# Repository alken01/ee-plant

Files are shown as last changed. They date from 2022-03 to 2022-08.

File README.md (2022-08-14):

# ee-plant 🌱
## EE5/IoT02
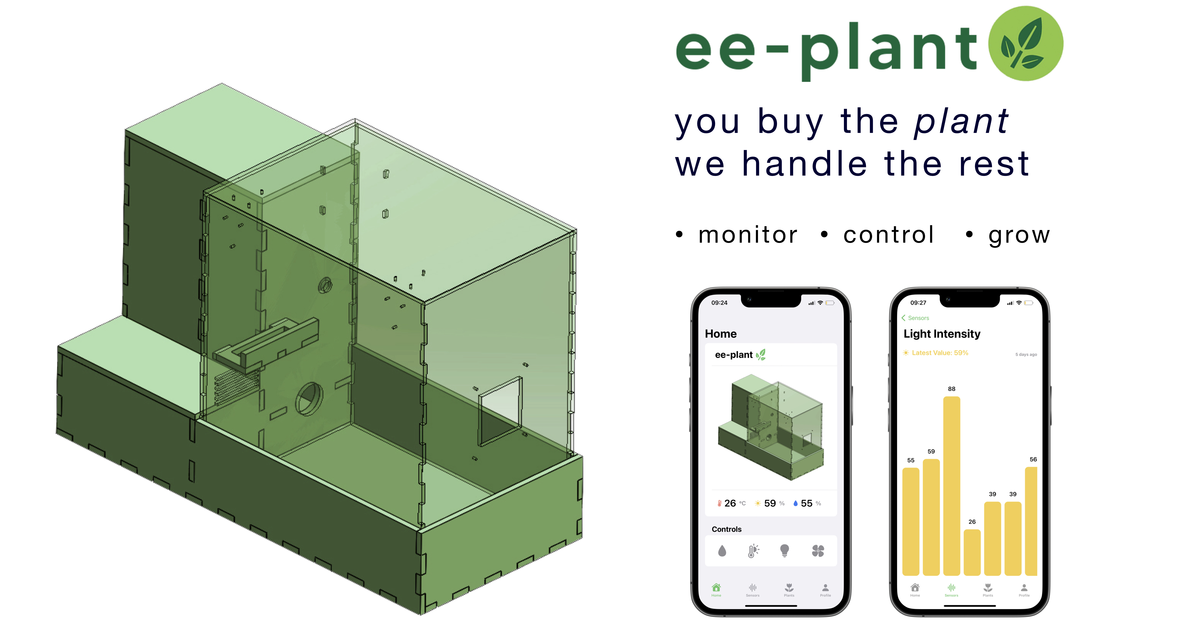
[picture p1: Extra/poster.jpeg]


### Intro
If you do not have the time to take care of your plants or when you are away from home for a few days, the ee-plant can help you! The system can look after different plant species, from common house plants to exotic ones. Specialised algorithms are designed with that in mind, tailored for every kind. 

The ee-plant comes with an Android app that updates the user about the plant. Is it too cold? The temperature goes up! Is it too dry? The system will water the plant. If the reservoir's water level is low, the app will notify the user.

Of course, you can take matters into your own hands and adjust every command accordingly.

### Sensors
The following sensors monitor the system 24/7:

- the soil moisture
- the air humidity
- temperature
- light intake

### Actuators
The following actuators regulate and control the system:

- a heater warms up the air
- a fan cools down the environment and regulates the humidity
- a spray machine, connected to a servo motor, sprays water and increase the humidity
- the water reservoir, attached with a pump and a servo motor, waters the soil

### Finally
The system's exterior is made out of a plexiglass box, MDF and 3D printed components. A power bank supplies the system with 5V. The ESP32 communicates with the database in the server through its Wi-Fi module. Data from the sensors is saved in these databases. It is then made available to the user via the app in form of graphs over time

> With the ee-plant everything is about nature and comfort.

## Sprints

### Sprint 1
In sprint 1 we worked mainly on the system's sensors.
The following user stories were closed:

- As a user I want to organise the data in databases
- As a user I want to know the temperature
- As a user I want to know the humidity and the moisture
- As a user I want to know the water level of the reservoir
- As a user I want to know if the plant is in light

[Video Sprint 1](https://kuleuven.mediaspace.kaltura.com/media/EE5+Team+IoT+2+-+Sprint+1/1_wgv9ouep)

### Sprint 2

The following user stories were closed:

- As a user I want to know the water level of the reservoir
- As a user I want to know if the plant is in light
- As a user I want to know the humidity and the moisture
- As a user I want to know the temperature
- As a user I want to organise the data in databases
- As a user I want a nice exterior design/case

Progress was made in the following:

- As a user I want to have a custom REST API
- As a user I want an Android App to control the device
- As a user I want to control the lighting

[Video Sprint 2](https://kuleuven.mediaspace.kaltura.com/media/EE5+Team+IoT+2+-+Sprint+2/1_kdvxv84o)

### Sprint 3

The following user stories were closed:

- As a user I want an iOS app to control the device
- As a user I want to have a smart device
- As a user I want everything to fit in the same case
- As a user I want to water the plant
- As a user I want to have web connectivity
- As a user I want to have as minimal wiring as possible (PCB)

[Video Sprint 3](https://kuleuven.mediaspace.kaltura.com/media/ee-plant+sprint+3+bew/1_60p68z9a)

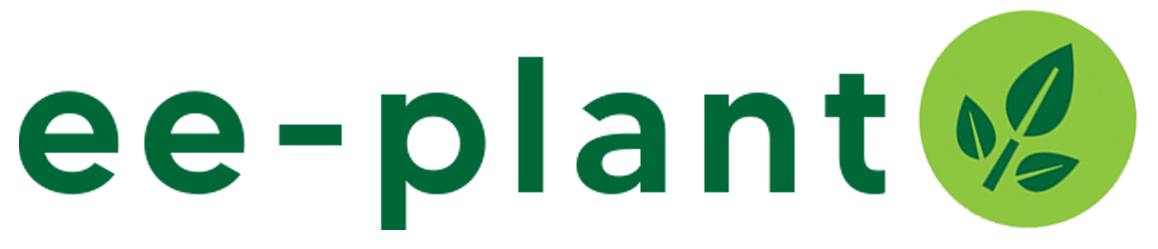
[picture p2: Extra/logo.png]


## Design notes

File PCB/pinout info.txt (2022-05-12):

Tussen twee pinnen 2,54 mm
Lengte van een rij = 11*2.54 = 27.94
Verticaal van elkaar verwijderd = 21.65

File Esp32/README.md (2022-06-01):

# _Sample project_

(See the README.md file in the upper level 'examples' directory for more information about examples.)

This is the simplest buildable example. The example is used by command `idf.py create-project`
that copies the project to user specified path and set it's name. For more information follow the [docs page](https://docs.espressif.com/projects/esp-idf/en/latest/api-guides/build-system.html#start-a-new-project)

## How to use example
We encourage the users to use the example as a template for the new projects.
A recommended way is to follow the instructions on a [docs page](https://docs.espressif.com/projects/esp-idf/en/latest/api-guides/build-system.html#start-a-new-project).

## Example folder contents

The project **sample_project** contains one source file in C language [main.c](main/AirHumidity.c). The file is located in folder [main](main).

ESP-IDF projects are built using CMake. The project build configuration is contained in `CMakeLists.txt`
files that provide set of directives and instructions describing the project's source files and targets
(executable, library, or both). 

Below is short explanation of remaining files in the project folder.

```
├── CMakeLists.txt
├── main
│   ├── CMakeLists.txt
│   └── main.c
└── README.md                  This is the file you are currently reading
```
Additionally, the sample project contains Makefile and component.mk files, used for the legacy Make based build system. 
They are not used or needed when building with CMake and idf.py.

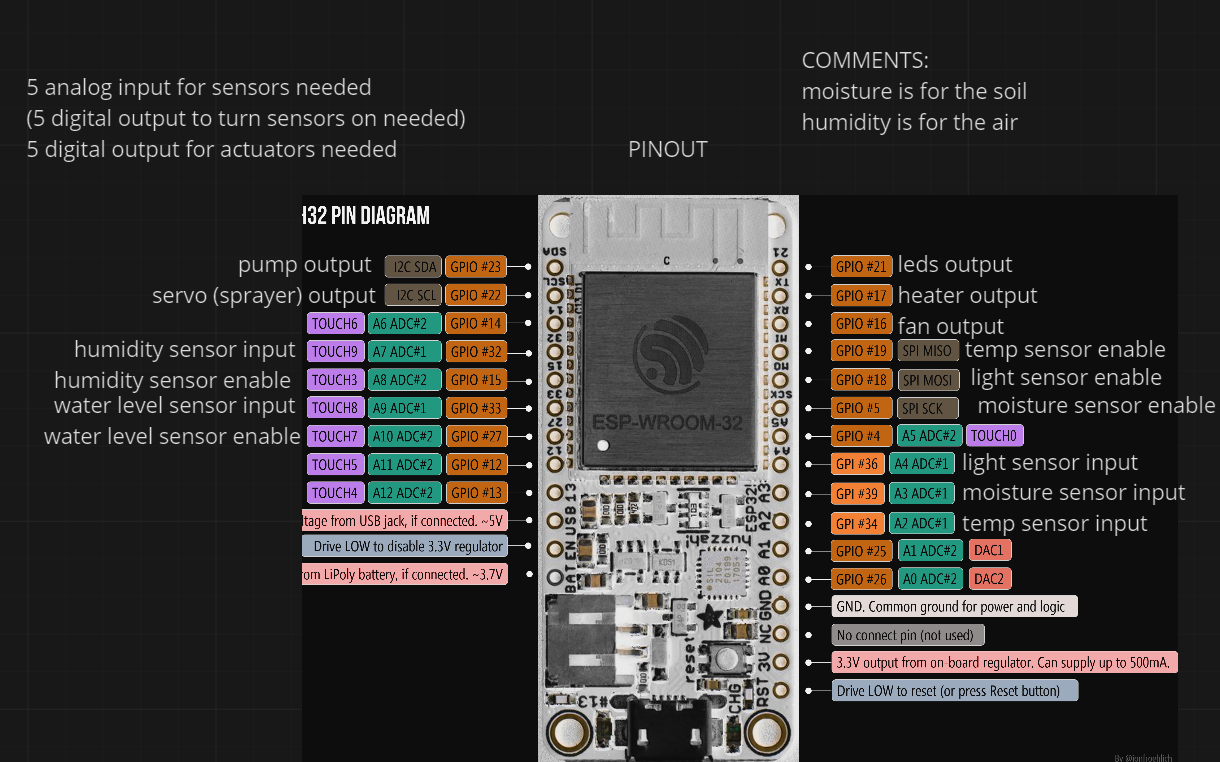
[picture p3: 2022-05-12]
PCB/image.png

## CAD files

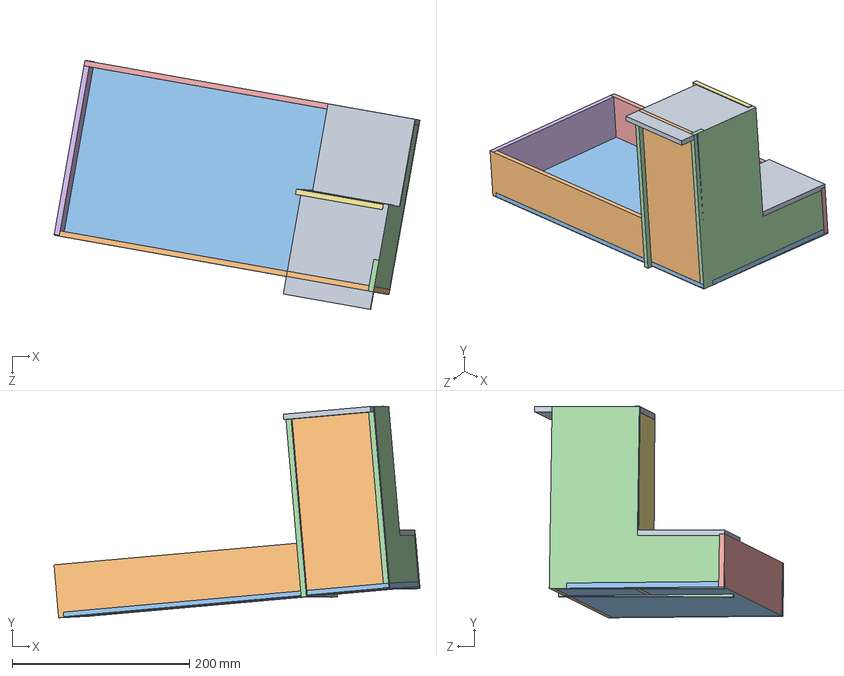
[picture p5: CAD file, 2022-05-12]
SolidWorks/Assembly 22.02.19.SLDASM
412.8 x 238.8 x 280.7 mm
PlantFront
PlantBottom
ReservoirFront x 2
PlantBack
ReservoirCover x 2
PlantSide
ReservoirSExtraLong

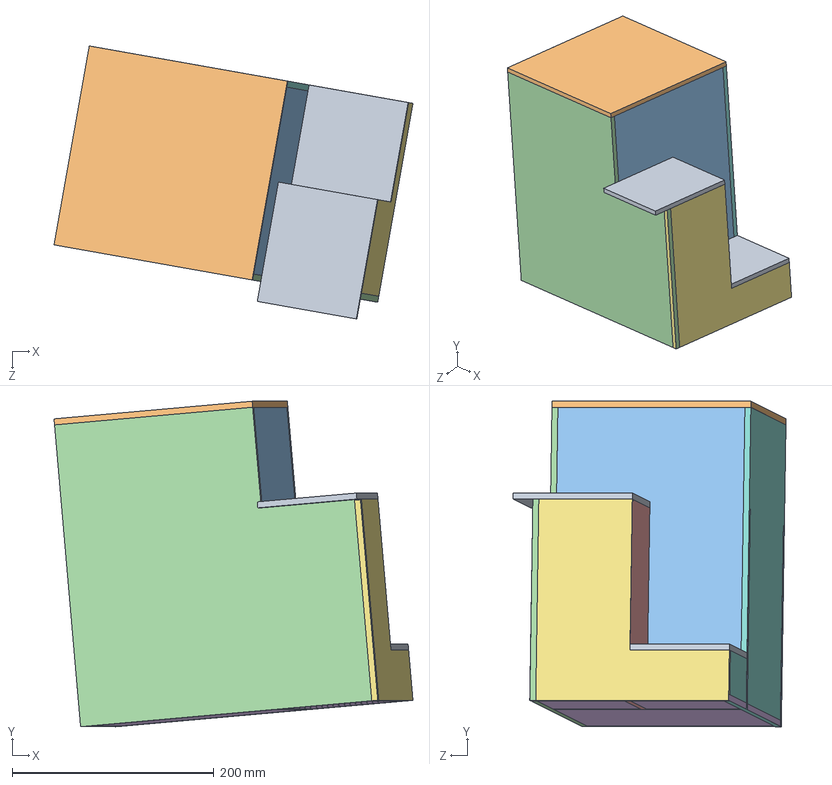
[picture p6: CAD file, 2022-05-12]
SolidWorks/Assembly1.SLDASM
355.5 x 322.4 x 270.4 mm
PlantSide x 2
PlantCover
PlantFront
ReservoirSExtraLong
PlantBottom
ReservoirFront
PlantBack
ReservoirCover x 2

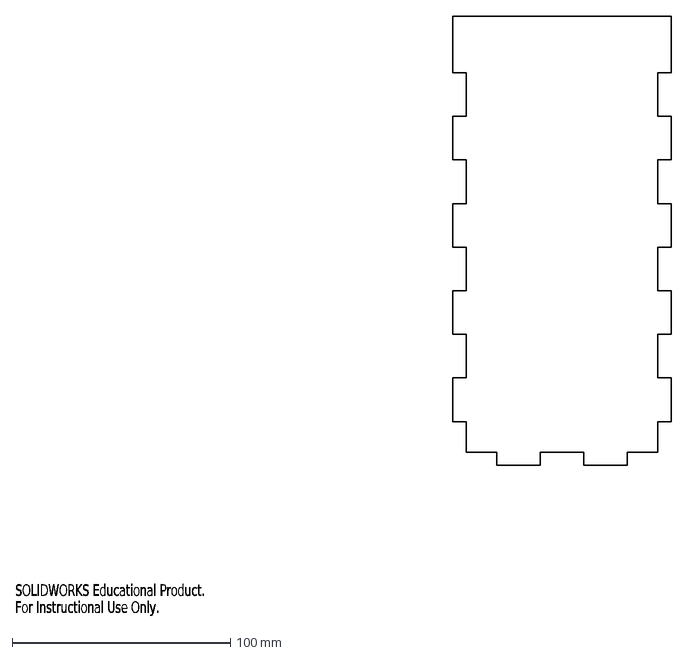
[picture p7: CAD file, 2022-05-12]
SolidWorks/drawings/ReservoirS.DXF
SOLIDWORKS Educational Product.
For Instructional Use Only.

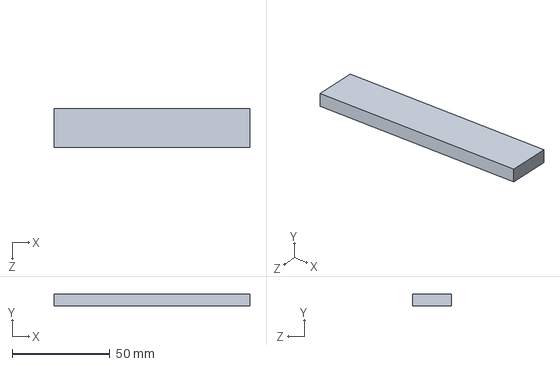
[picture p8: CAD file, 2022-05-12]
SolidWorks/Parts/FootballLight.SLDPRT
100.0 x 6.00 x 20.0 mm

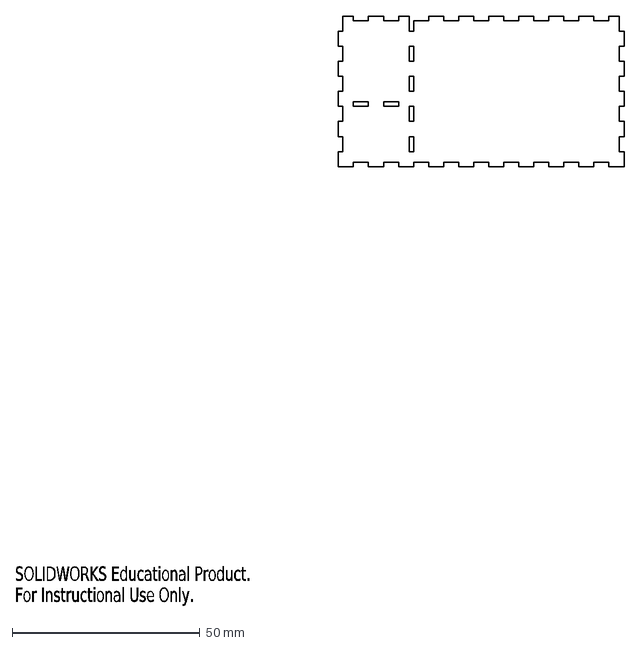
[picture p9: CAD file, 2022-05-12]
SolidWorks/drawings/PlantBottom.DXF
SOLIDWORKS Educational Product.
For Instructional Use Only.

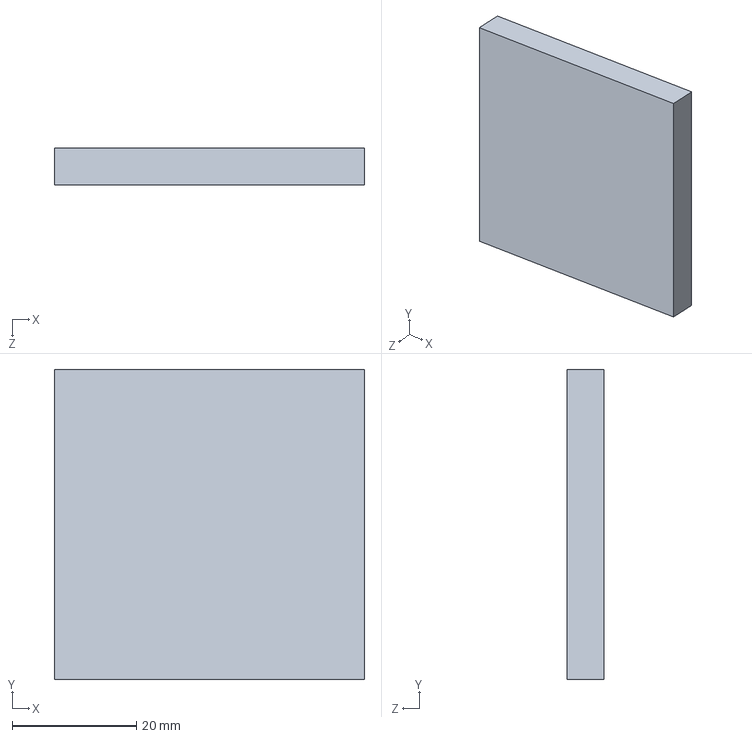
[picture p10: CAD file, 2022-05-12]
SolidWorks/Parts/ElectronicsSide.SLDPRT
50.0 x 50.0 x 6.00 mm

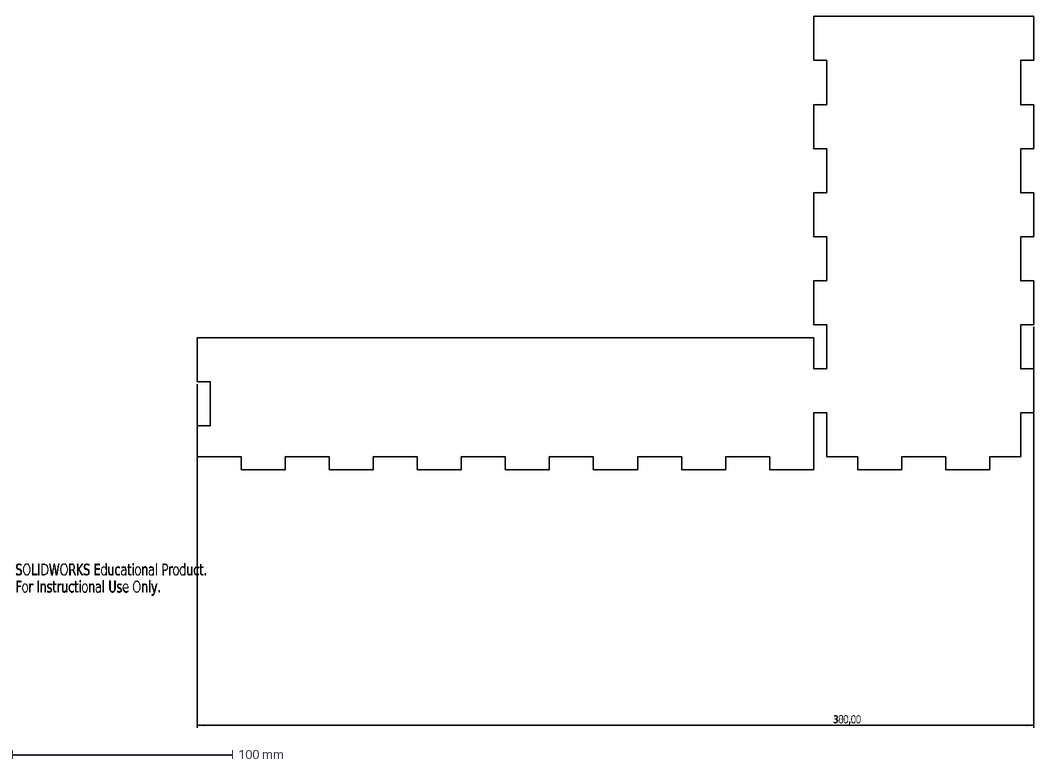
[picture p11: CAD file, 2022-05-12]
SolidWorks/drawings/PlantFront.DXF
380,00
SOLIDWORKS Educational Product.
For Instructional Use Only.

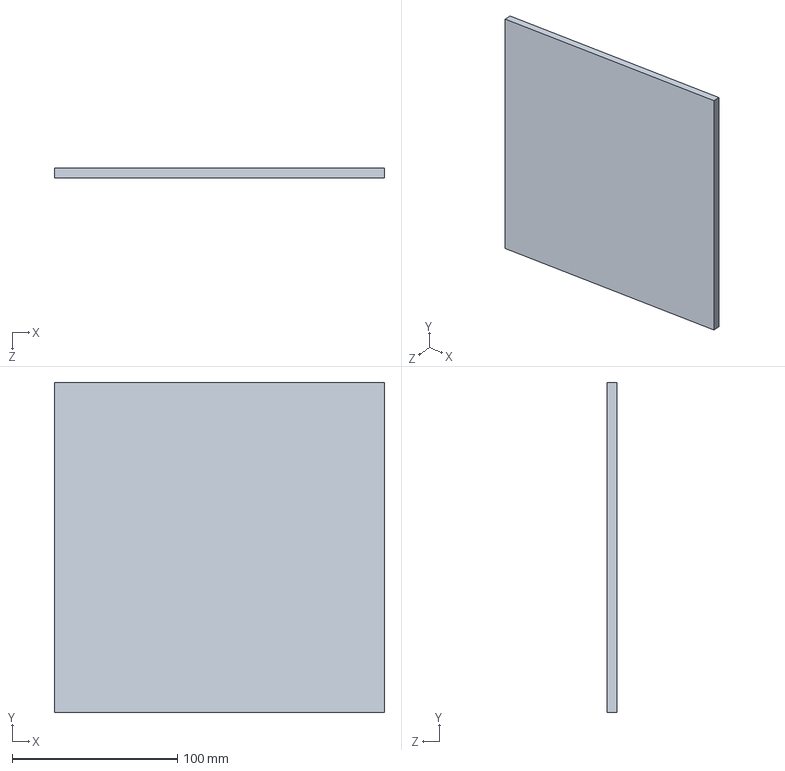
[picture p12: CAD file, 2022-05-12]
SolidWorks/Parts/PlantCover.SLDPRT
200.0 x 200.0 x 6.00 mm

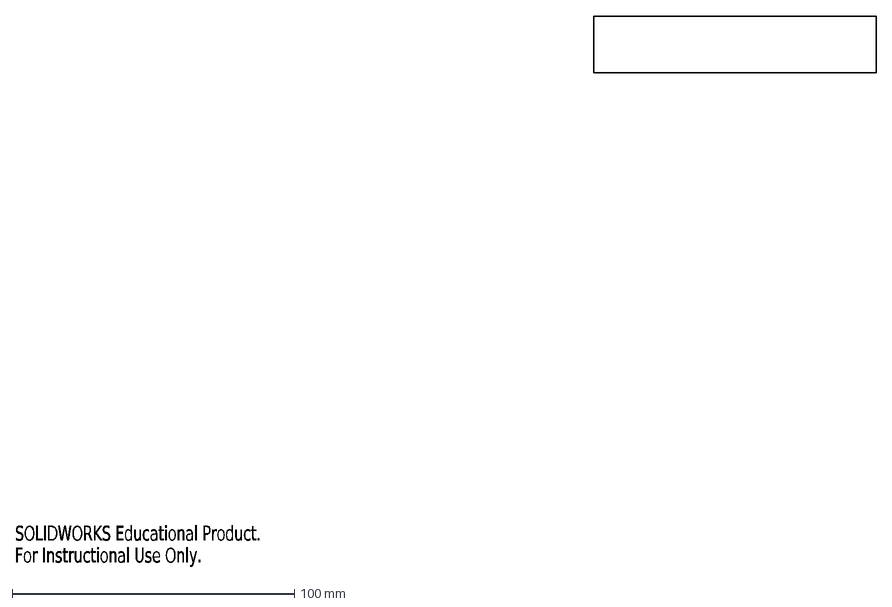
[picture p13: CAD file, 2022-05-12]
SolidWorks/drawings/FootballLight.DXF
SOLIDWORKS Educational Product.
For Instructional Use Only.

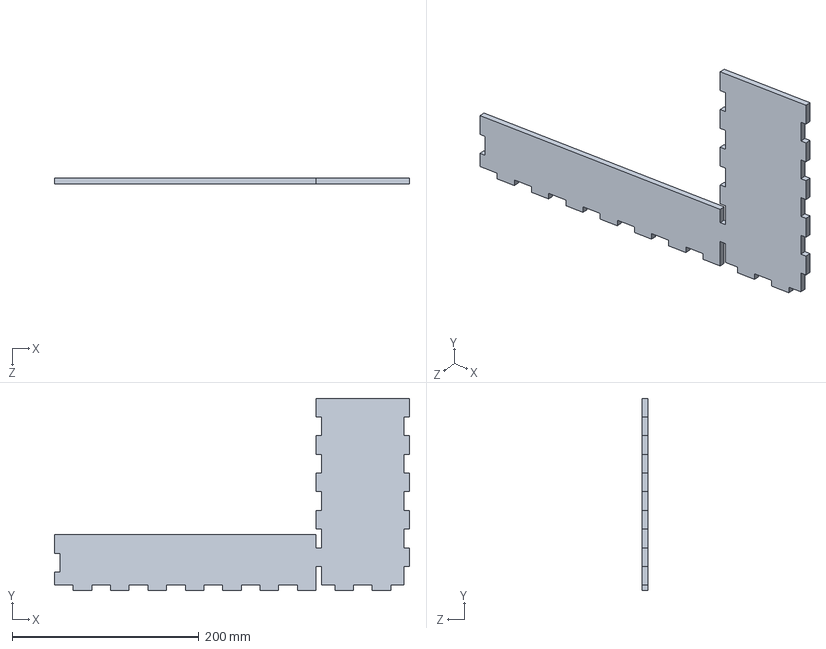
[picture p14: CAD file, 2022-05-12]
SolidWorks/Parts/PlantFront.SLDPRT
380.0 x 206.0 x 6.00 mm

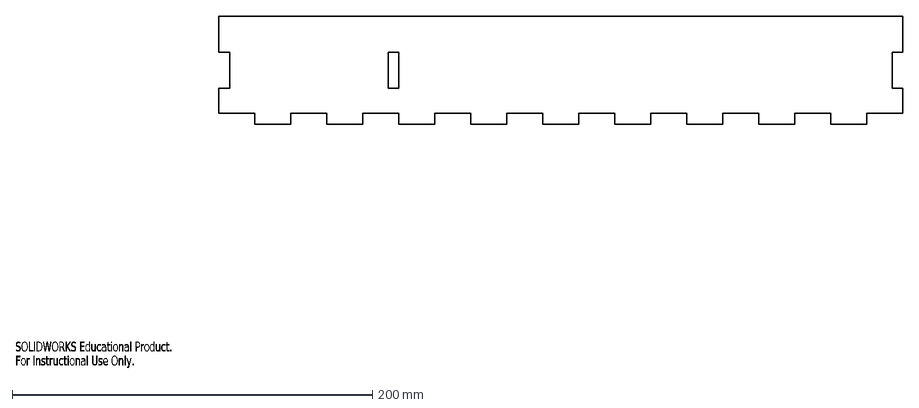
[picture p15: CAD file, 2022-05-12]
SolidWorks/drawings/PlantBack.DXF
SOLIDWORKS Educational Product.
For Instructional Use Only.

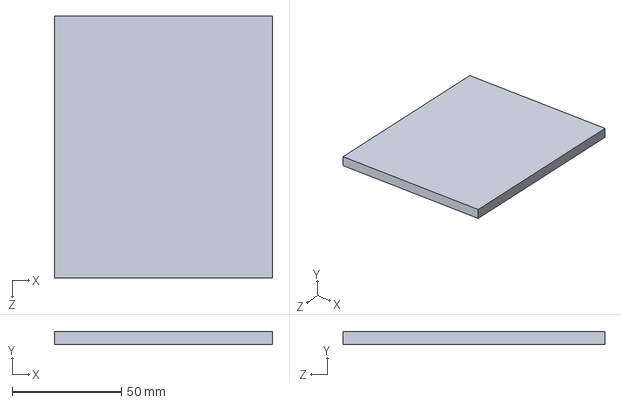
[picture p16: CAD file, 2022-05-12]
SolidWorks/Parts/ReservoirCover.SLDPRT
100.0 x 6.00 x 120.0 mm

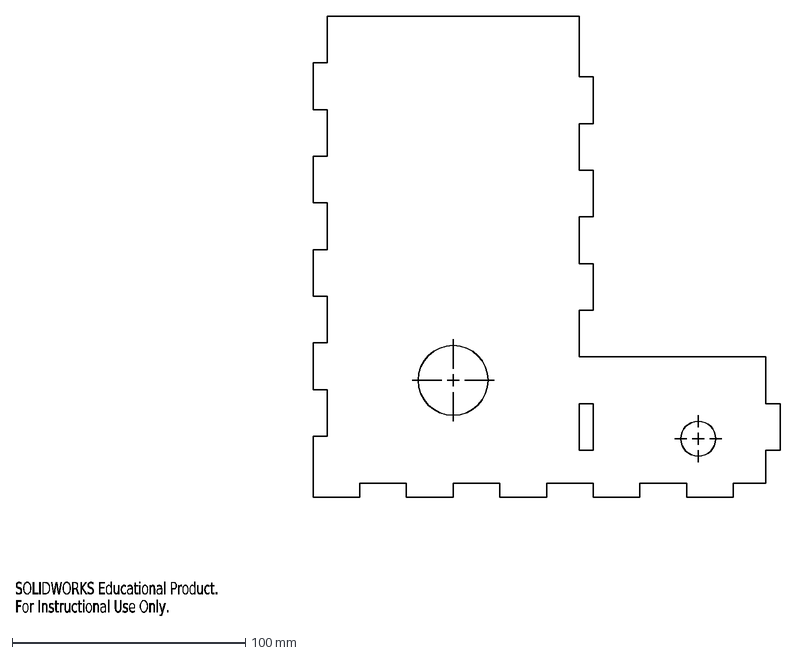
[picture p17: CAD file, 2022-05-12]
SolidWorks/drawings/ReservoirFront.DXF
SOLIDWORKS Educational Product.
For Instructional Use Only.

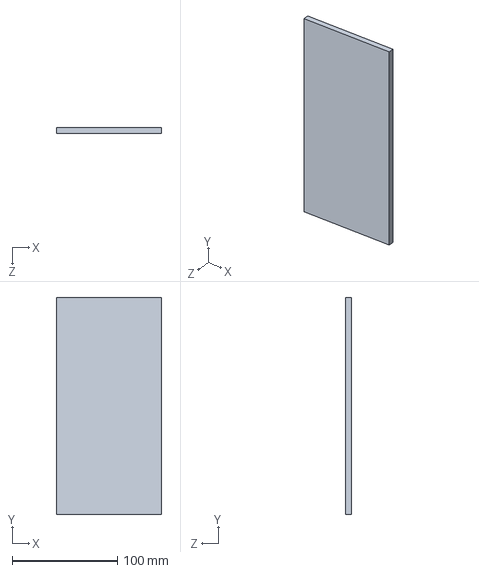
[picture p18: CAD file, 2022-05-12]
SolidWorks/Parts/ReservoirSExtraLong.SLDPRT
100.0 x 206.0 x 6.00 mm

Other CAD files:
SolidWorks/drawings/PlantCover.DXF
SolidWorks/Parts/ReservoirFrontNoHoles.SLDPRT
SolidWorks/drawings/ReservoirCover.DXF
SolidWorks/Parts/ElectronicsCover.SLDPRT
SolidWorks/Parts/ElectronicsFrontBack.SLDPRT
SolidWorks/Parts/MDFSide.SLDPRT
SolidWorks/Parts/PlantBack.SLDPRT
SolidWorks/Parts/PlantBottom.SLDPRT
SolidWorks/Parts/PlantSide.SLDPRT
SolidWorks/Parts/PlexiCover.SLDPRT
SolidWorks/Parts/PlexiFront.SLDPRT
SolidWorks/Parts/PlexiFrontNoHOles.SLDPRT
SolidWorks/Parts/ReservoirFront.SLDPRT
SolidWorks/Parts/ReservoirS.SLDPRT
SolidWorks/drawings/ElectronicsCover.DXF
SolidWorks/drawings/PlantSide.DXF
SolidWorks/drawings/ReservoirFront.SLDDRW
SolidWorks/drawings/ReservoirFrontNoHoles.DXF
SolidWorks/drawings/ReservoirSExtraLong.DXF

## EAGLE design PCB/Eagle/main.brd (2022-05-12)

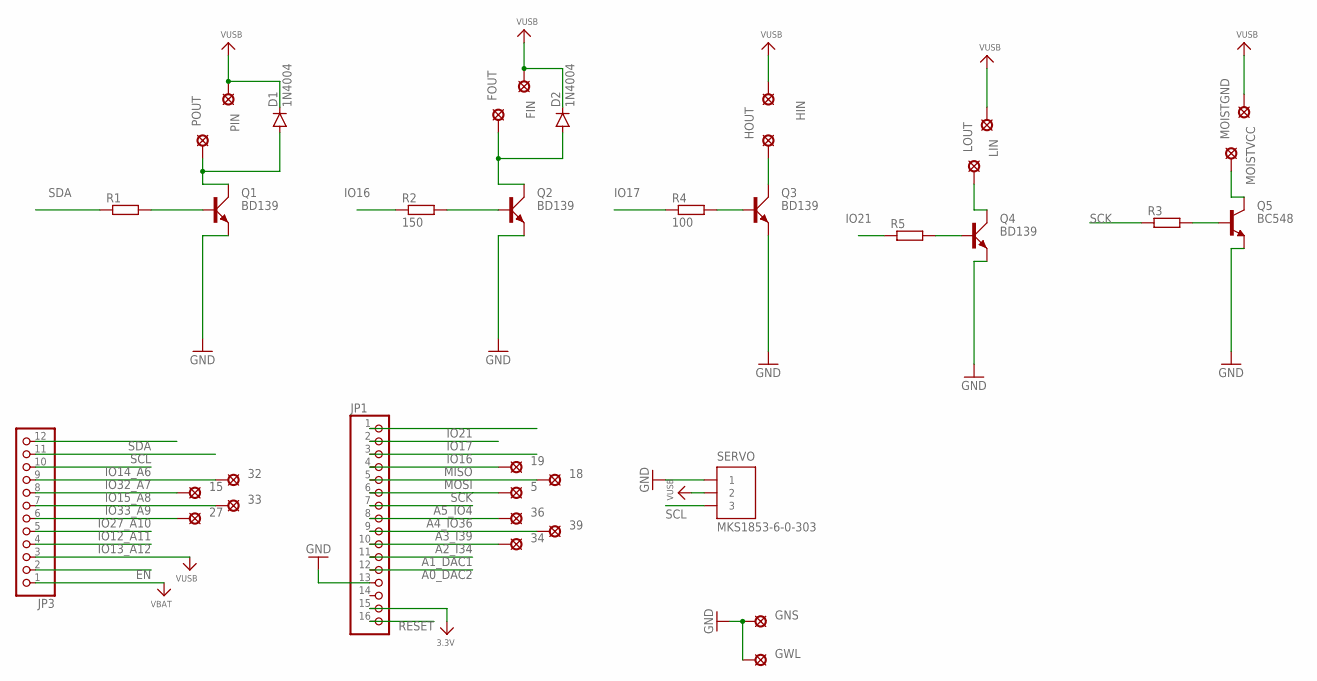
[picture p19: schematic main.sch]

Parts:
5, 15, 18, 19, 27, 32, 33, 34, 36, 39: SE13
D1, D2: 1N4004; DO41-10
FIN: SE13
FOUT: SE13
GNS: SE13
GWL: SE13
HIN: SE13
HOUT: SE13
JP1: HEADER-1X16_MIN; 1X16_ROUND_MIN
JP3: HEADER-1X12_MIN; 1X12_ROUND_MIN
LIN: SE13
LOUT: SE13
MOISTGND: SE13
MOISTVCC: SE13
PIN: SE13
POUT: SE13
Q1, Q2, Q3, Q4: BD139; TO126AV
Q5: BC548; TO92-EBC
R1, R3, R5: R-EU_R0805; R0805
R2: 150; R0805
R4: 100; R0805
SERVO: MKS1853-6-0-303

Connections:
3.3V: JP1.15
A0_DAC2: JP1.12
A1_DAC1: JP1.11
A2_I34: 34.MP, JP1.10
A3_I39: 39.MP, JP1.9
A4_IO36: 36.MP, JP1.8
A5_IO4: JP1.7
EN: JP3.2
GND: GNS.MP, GWL.MP, JP1.13, Q1.E, Q2.E, Q3.E, Q4.E, Q5.E, SERVO.1
IO12_A11: JP3.5
IO13_A12: JP3.4
IO14_A6: JP3.10
IO15_A8: 15.MP, JP3.8
IO16: JP1.3, R2.1
IO17: JP1.2, R4.1
IO21: JP1.1, R5.1
IO27_A10: 27.MP, JP3.6
IO32_A7: 32.MP, JP3.9
IO33_A9: 33.MP, JP3.7
MISO: 19.MP, JP1.4
MOSI: 18.MP, JP1.5
unnamed: Q4.B, R5.2
unnamed: Q3.B, R4.2
unnamed: LOUT.MP, Q4.C
unnamed: HOUT.MP, Q3.C
unnamed: D2.A, FOUT.MP, Q2.C
unnamed: Q2.B, R2.2
unnamed: D1.A, POUT.MP, Q1.C
unnamed: Q1.B, R1.2
unnamed: Q5.B, R3.2
unnamed: MOISTGND.MP, Q5.C
RESET: JP1.16
SCK: 5.MP, JP1.6, R3.1
SCL: JP3.11, SERVO.3
SDA: JP3.12, R1.1
VBAT: JP3.1
VBUS: D1.C, D2.C, FIN.MP, HIN.MP, JP3.3, LIN.MP, MOISTVCC.MP, PIN.MP, SERVO.2

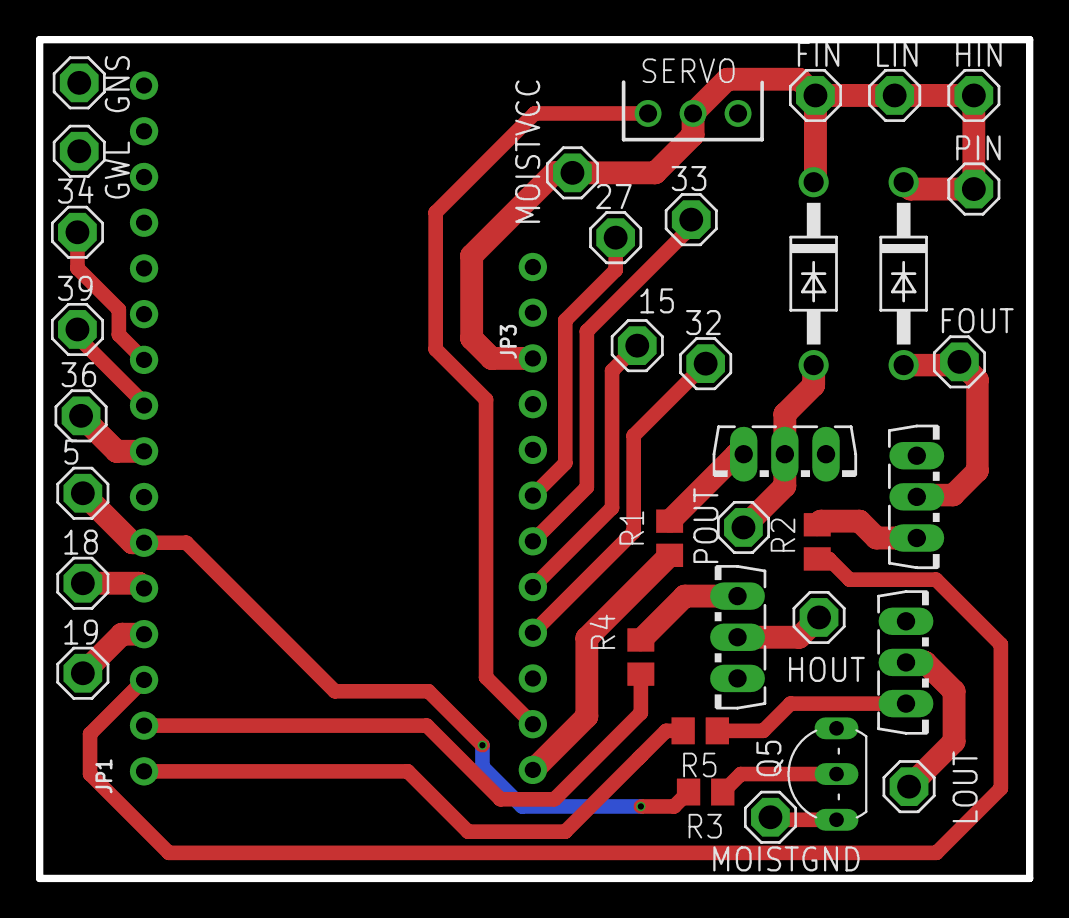
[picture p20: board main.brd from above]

Board: 2 copper layers, 55.0 x 46.6 mm, 37 parts (0 on the bottom side), 27 nets.

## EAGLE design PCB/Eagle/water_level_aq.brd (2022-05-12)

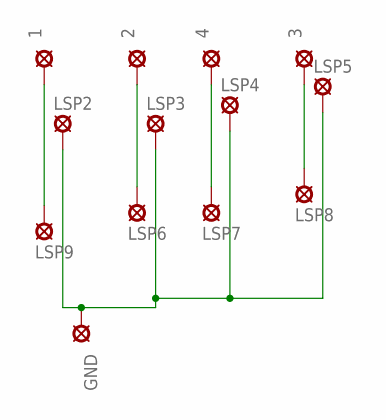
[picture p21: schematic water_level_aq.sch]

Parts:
1, 2, 3, 4: SE13
GND: SE13
LSP2, LSP3, LSP4, LSP5, LSP6, LSP7, LSP8, LSP9: MCS10B

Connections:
unnamed: 1.MP, LSP9.MP
unnamed: GND.MP, LSP2.MP, LSP3.MP, LSP4.MP, LSP5.MP
unnamed: 2.MP, LSP6.MP
unnamed: 4.MP, LSP7.MP
unnamed: 3.MP, LSP8.MP

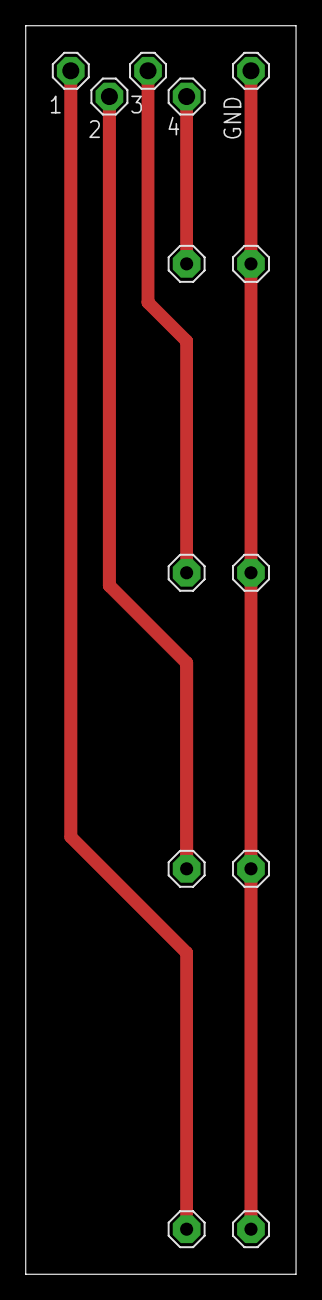
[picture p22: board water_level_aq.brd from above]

Board: 2 copper layers, 21.0 x 97.0 mm, 13 parts (0 on the bottom side), 5 nets.

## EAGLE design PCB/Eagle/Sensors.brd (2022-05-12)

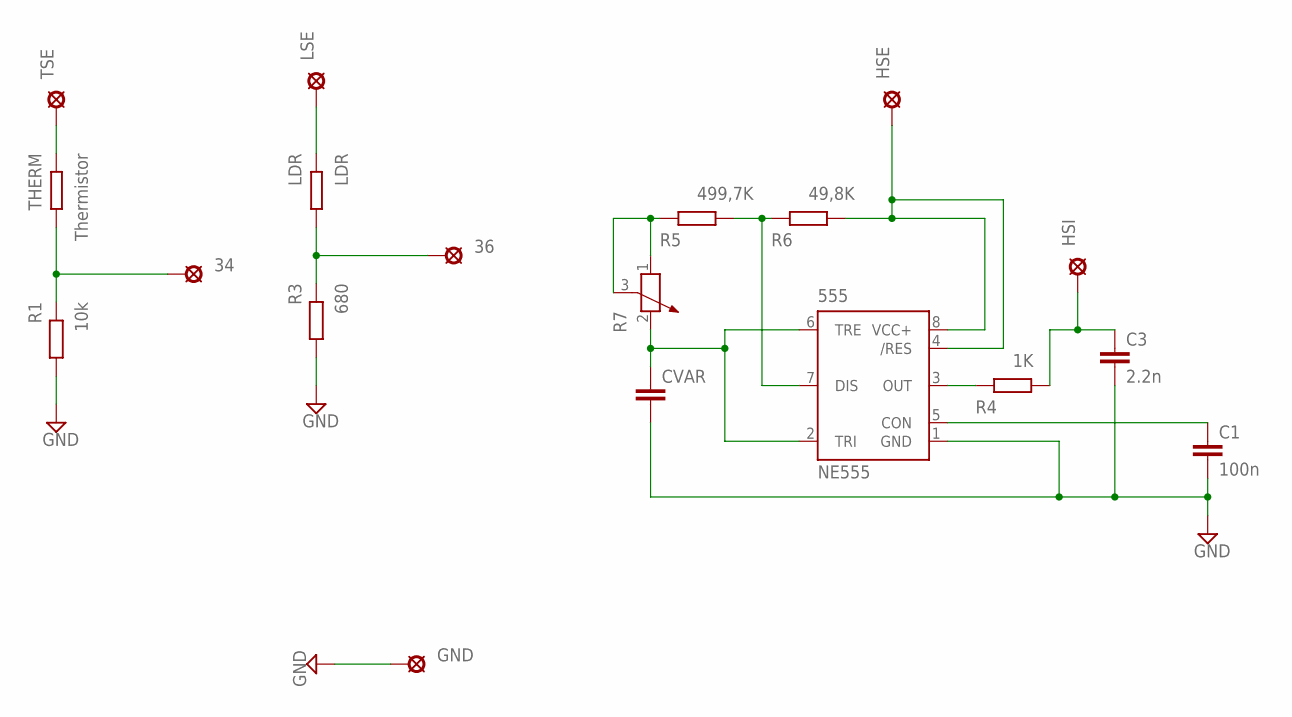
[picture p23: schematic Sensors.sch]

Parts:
34: SE13
36: 36; SE13
555: NE555; DIL-08
C1: 100n; C0805
C3: 2.2n; C0805
CVAR: C-EU050-025X075; C050-025X075
GND: SE13
HSE: SE13
HSI: SE13
LDR: LDR; WEERSTAND
LSE: SE13
R1: 10k; R0805
R3: 680; R0805
R4: 1K; R0805
R5: 499,7K; R0805
R6: 49,8K; R0805
R7: POTENTIOMETER_PT-10; PT-10
THERM: Thermistor; WEERSTAND
TSE: SE13

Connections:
34: 34.MP, R1.1, THERM.P$2
36: 36.MP, LDR.P$2, R3.1
GND: 555.1 (GND), C1.2, C3.2, CVAR.2, GND.MP, R1.2, R3.2
unnamed: THERM.P$1, TSE.MP
unnamed: LDR.P$1, LSE.MP
unnamed: 555.5 (CON), C1.1
unnamed: C3.1, HSI.MP, R4.2
unnamed: 555.3 (OUT), R4.1
unnamed: 555.4 (/RES), 555.8 (VCC+), HSE.MP, R6.2
unnamed: 555.2 (TRI), 555.6 (TRE), CVAR.1, R7.2
unnamed: R5.1, R7.1, R7.3
unnamed: 555.7 (DIS), R5.2, R6.1

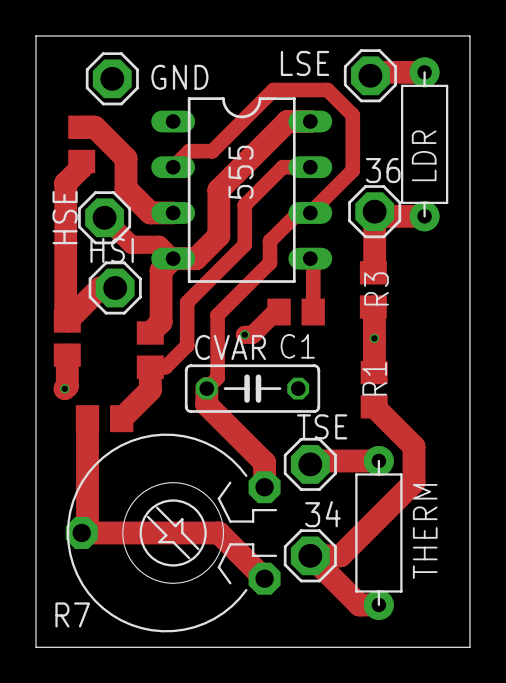
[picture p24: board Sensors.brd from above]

Board: 2 copper layers, 24.1 x 34.0 mm, 19 parts (0 on the bottom side), 12 nets.

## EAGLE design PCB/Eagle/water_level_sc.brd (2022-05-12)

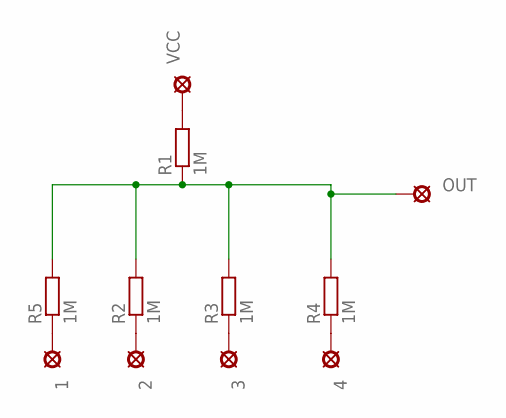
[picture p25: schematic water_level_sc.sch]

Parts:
1, 2, 3, 4: SE13
OUT: SE13
R1, R2, R3, R4, R5: 1M; R0805
VCC: SE13

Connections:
unnamed: 4.MP, R4.1
unnamed: 3.MP, R3.1
unnamed: 2.MP, R2.1
unnamed: 1.MP, R5.1
unnamed: R1.2, VCC.MP
unnamed: OUT.MP, R1.1, R2.2, R3.2, R4.2, R5.2

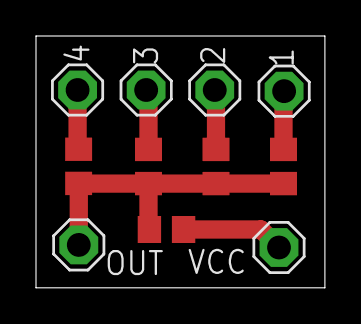
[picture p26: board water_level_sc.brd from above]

Board: 2 copper layers, 16.1 x 14.0 mm, 11 parts (0 on the bottom side), 6 nets.

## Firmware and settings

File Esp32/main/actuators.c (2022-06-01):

#include "appMain.h"
#include "actuators.h"
#include "water_pump.h"
#include <driver/ledc.h>


#define HEATER_OUTPUT_GPIO GPIO_NUM_17
#define FAN_OUTPUT_GPIO GPIO_NUM_16
#define LIGHT_OUTPUT_GPIO GPIO_NUM_21

ledc_channel_config_t ledc_heater_channel;



void config_heater_PWM(){
    ledc_timer_config_t ledc_timer = {
            .duty_resolution = LEDC_TIMER_13_BIT, // resolution of PWM duty
            .freq_hz = 5000,                      // frequency of PWM signal
            .speed_mode = LEDC_HIGH_SPEED_MODE,           // timer mode
            .timer_num = LEDC_TIMER_0,            // timer index
            .clk_cfg = LEDC_AUTO_CLK,              // Auto select the source clock
    };
    ledc_timer_config(&ledc_timer);

    ledc_heater_channel.channel = LEDC_CHANNEL_0;
    ledc_heater_channel.duty=0;
    ledc_heater_channel.gpio_num=HEATER_OUTPUT_GPIO;
    ledc_heater_channel.speed_mode=LEDC_HIGH_SPEED_MODE;
    ledc_heater_channel.hpoint=0;
    ledc_heater_channel.timer_sel=LEDC_TIMER_0;
    ledc_heater_channel.flags.output_invert=0;
    ledc_channel_config(&ledc_heater_channel);
}

void set_heater_pwm()
{
    ledc_set_duty(ledc_heater_channel.speed_mode, ledc_heater_channel.channel, 4000);
    ledc_update_duty(ledc_heater_channel.speed_mode, ledc_heater_channel.channel);
}

void reset_heater_pwm()
{
    ledc_set_duty(ledc_heater_channel.speed_mode, ledc_heater_channel.channel, 0);
    ledc_update_duty(ledc_heater_channel.speed_mode, ledc_heater_channel.channel);
}


_Noreturn void start_actuators(void* arg){
    config_heater_PWM();


    int light_flag=0;
    int fan_flag=0;
    int water_flag=0;
    int heater_flag=0;

    double temperature_value=0;
    double soil_moisture_value=0;
    int water_level_value=0;
    double light_value=300;



    while(1){
        //read from queues:
        struct sensor_flag_struct sensor_flag_received;
        for(int i=0; i < 4; i++){
            xQueueReceive(flag_queue,&sensor_flag_received, 100);
            if(sensor_flag_received.sensor_ID==0){ //water
                water_flag=sensor_flag_received.sensor_flag;
            }
            else if(sensor_flag_received.sensor_ID==1){ //heater
                heater_flag= sensor_flag_received.sensor_flag;
            }
            else if(sensor_flag_received.sensor_ID==2){ //lights
                light_flag= sensor_flag_received.sensor_flag;
            }
            else if(sensor_flag_received.sensor_ID==3){ //fan
                fan_flag = sensor_flag_received.sensor_flag;
            }

        }

        struct sensor_data_struct sensor_data_received;
        for(int i=0; i<4;i++){
            xQueueReceive(adc_queue,&sensor_data_received, 100);

            if(sensor_data_received.sensor_ID==1){
                temperature_value=sensor_data_received.sensor_value;
            }
            else if(sensor_data_received.sensor_ID==5){
                soil_moisture_value=sensor_data_received.sensor_value;
            }
            else if(sensor_data_received.sensor_ID==2){
                light_value=sensor_data_received.sensor_value;
            }
            else if(sensor_data_received.sensor_ID==4){
                water_level_value=(int)sensor_data_received.sensor_value;
            }

        }



        //actuator logic:
        gpio_set_direction(LIGHT_OUTPUT_GPIO, GPIO_MODE_OUTPUT);
        if(light_value<40 || light_flag==1){
            gpio_set_level(LIGHT_OUTPUT_GPIO, 1);
        }
        else{
            gpio_set_level(LIGHT_OUTPUT_GPIO, 0);//disable fan
        }

        gpio_set_direction(FAN_OUTPUT_GPIO, GPIO_MODE_OUTPUT);
        if(temperature_value>25.0){
            gpio_set_level(FAN_OUTPUT_GPIO, 1);
            reset_heater_pwm();
        }
        else{
            gpio_set_level(FAN_OUTPUT_GPIO, 0);//disable fan
            set_heater_pwm();//enable heating element
        }

        if(fan_flag==1){
            gpio_set_level(FAN_OUTPUT_GPIO, 1);
        }
        if(heater_flag == 1){
            set_heater_pwm();//enable heating element
        }


        if((soil_moisture_value>30 || water_flag==1) && water_level_value>300){ //if its dry and there is water or if the flag is set and there is water
            //water_for_5s();
        }

    }

}

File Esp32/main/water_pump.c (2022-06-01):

#include <stdio.h>
#include "freertos/FreeRTOS.h"
#include "freertos/task.h"
#include "driver/gpio.h"
#include "freertos/timers.h"
#include "water_pump.h"

#define PUMP_GPIO   GPIO_NUM_23
TimerHandle_t  timer_pump = NULL;


void pump_config(void)
{
    gpio_reset_pin(PUMP_GPIO);
    gpio_set_direction( PUMP_GPIO , GPIO_MODE_OUTPUT);
    gpio_set_level(PUMP_GPIO, 0);
}

void myTimerCallBack(TimerHandle_t xTimer){
    gpio_set_level(PUMP_GPIO, 0);
    xTimerDelete(timer_pump,10);
}

void water_for_5s(void)
{
    pump_config();
    gpio_set_level(PUMP_GPIO, 1);
    timer_pump = xTimerCreate("Timer_pump", pdMS_TO_TICKS(5*1000), pdFALSE, (void *) 1, myTimerCallBack);
    xTimerStart(timer_pump, 0);
}

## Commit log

2022-03-10 Added sample project
2022-03-14 Updated sensor
2022-03-29 Update: add sample project
2022-03-30 PWM working
2022-04-10 water pump and water level sensing
2022-04-10 water pump and water level sensing V2
2022-04-11 Only ESP32
2022-04-21 insert air humidity c file
2022-04-21 add stop_humidity as an exit point for the humidity sensor
2022-05-12 Added some extra files
    [Assembly 22.02.19.SLDASM, Assembly1.SLDASM, Assembly2.0.SLDASM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]

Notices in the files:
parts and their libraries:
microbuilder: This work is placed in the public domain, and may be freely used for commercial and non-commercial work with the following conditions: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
